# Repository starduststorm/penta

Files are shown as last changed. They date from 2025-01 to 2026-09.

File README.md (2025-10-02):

# penta

PCB designs and code for a Five-pointed star circumscribed within a circle of 55 pixels, for a total of 5³=125 pixels.

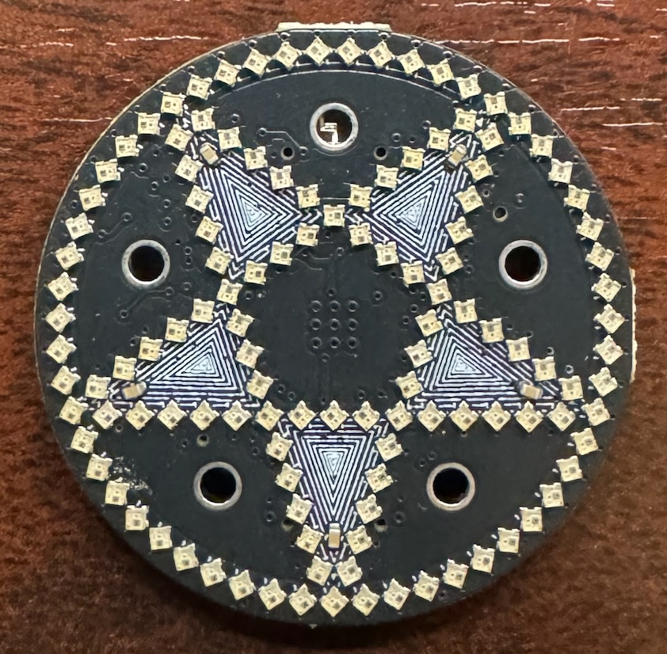
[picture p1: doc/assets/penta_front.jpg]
photo of front of penta

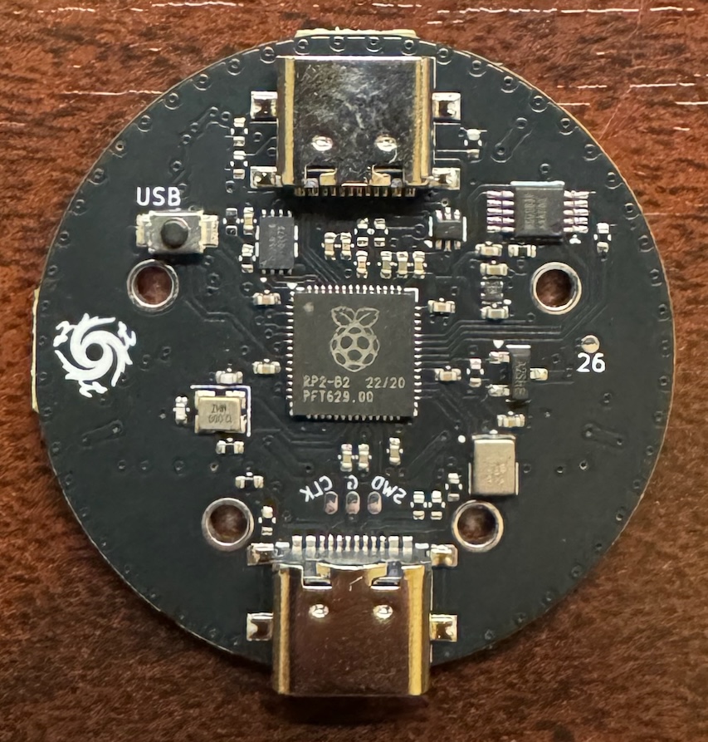
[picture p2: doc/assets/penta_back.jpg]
photo of back of penta


## Controls

The Five through-hole circles on the penta are touch-reactive and used to set the pattern.

## Hardware

* RP2040 dual-core ARM processor
* T3902 microphone
* WS2812B-1010 pixels

# Project layout

* board/ contains the KiCad pcb project
* src/ all project-specific source
* lib/ a skeleton copy of [kissfft], and submodule dependency *dustlib*

The project is built using [PlatformIO] in Visual Studio Code.

## Building

Build the v2 environment in the [PlatformIO] project, which corresponds to the MakerFaire2025 hardware.

You will likely need to run
```
git submodule update --init
```
in the source after ```git clone``` in order to fetch the submodule for building.

### Libraries & Dependencies
PlatformIO should fetch the apprpriate version of each dependency on first build.

* [FastLED] - A library for fast 8-bit math and rendering colors onto pixels
* [kissfft] - A simple library used to compute an fft on audio samples
* [dustlib] - My work-in-progress pixel library

[FastLED]: https://github.com/FastLED/FastLED
[PlatformIO]: <https://platformio.org>
[kissfft]: <https://github.com/mborgerding/kissfft>
[dustlib]: <https://github.com/starduststorm/dustlib>

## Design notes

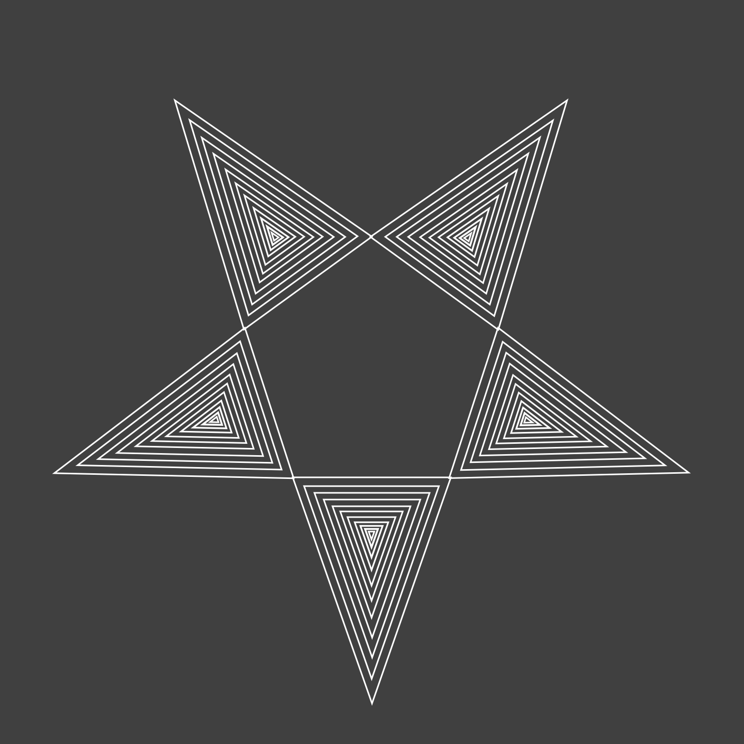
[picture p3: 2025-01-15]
board/assets/penta-brd-decor.png

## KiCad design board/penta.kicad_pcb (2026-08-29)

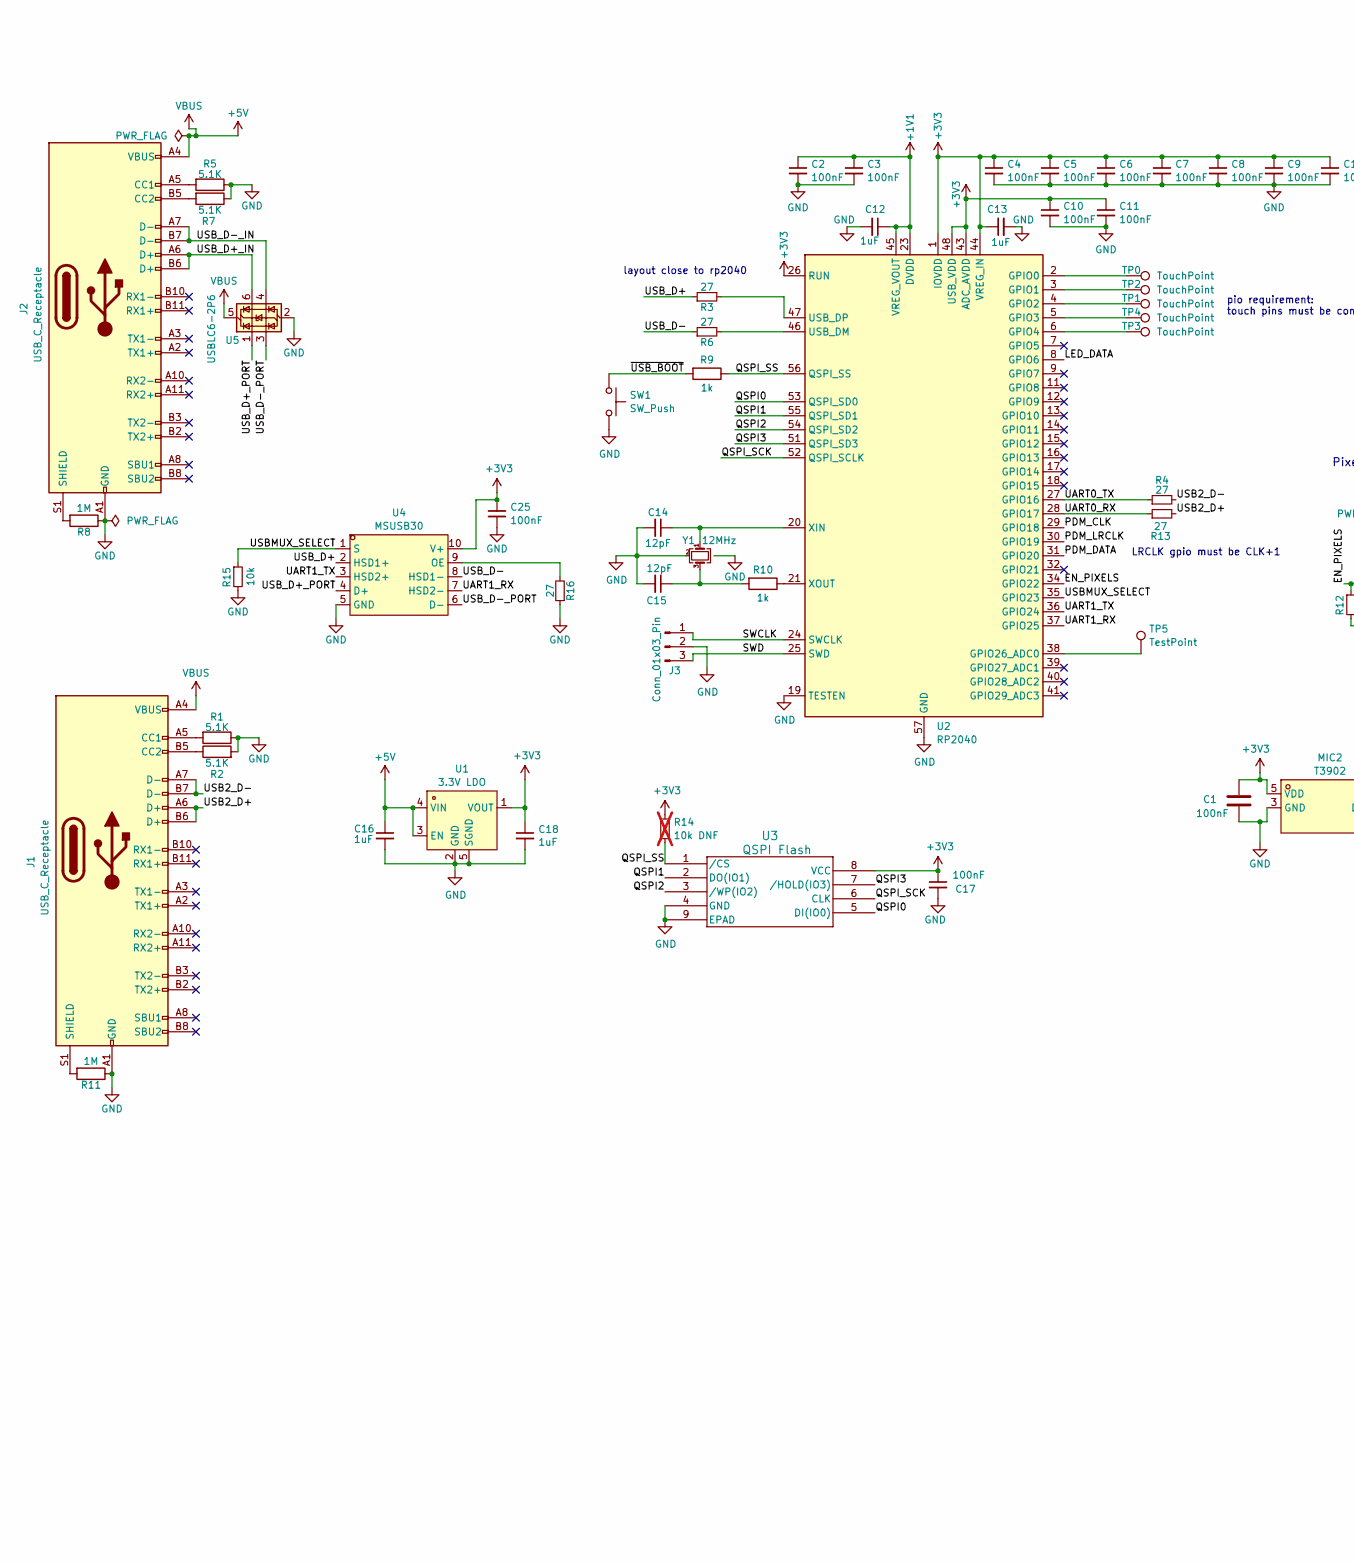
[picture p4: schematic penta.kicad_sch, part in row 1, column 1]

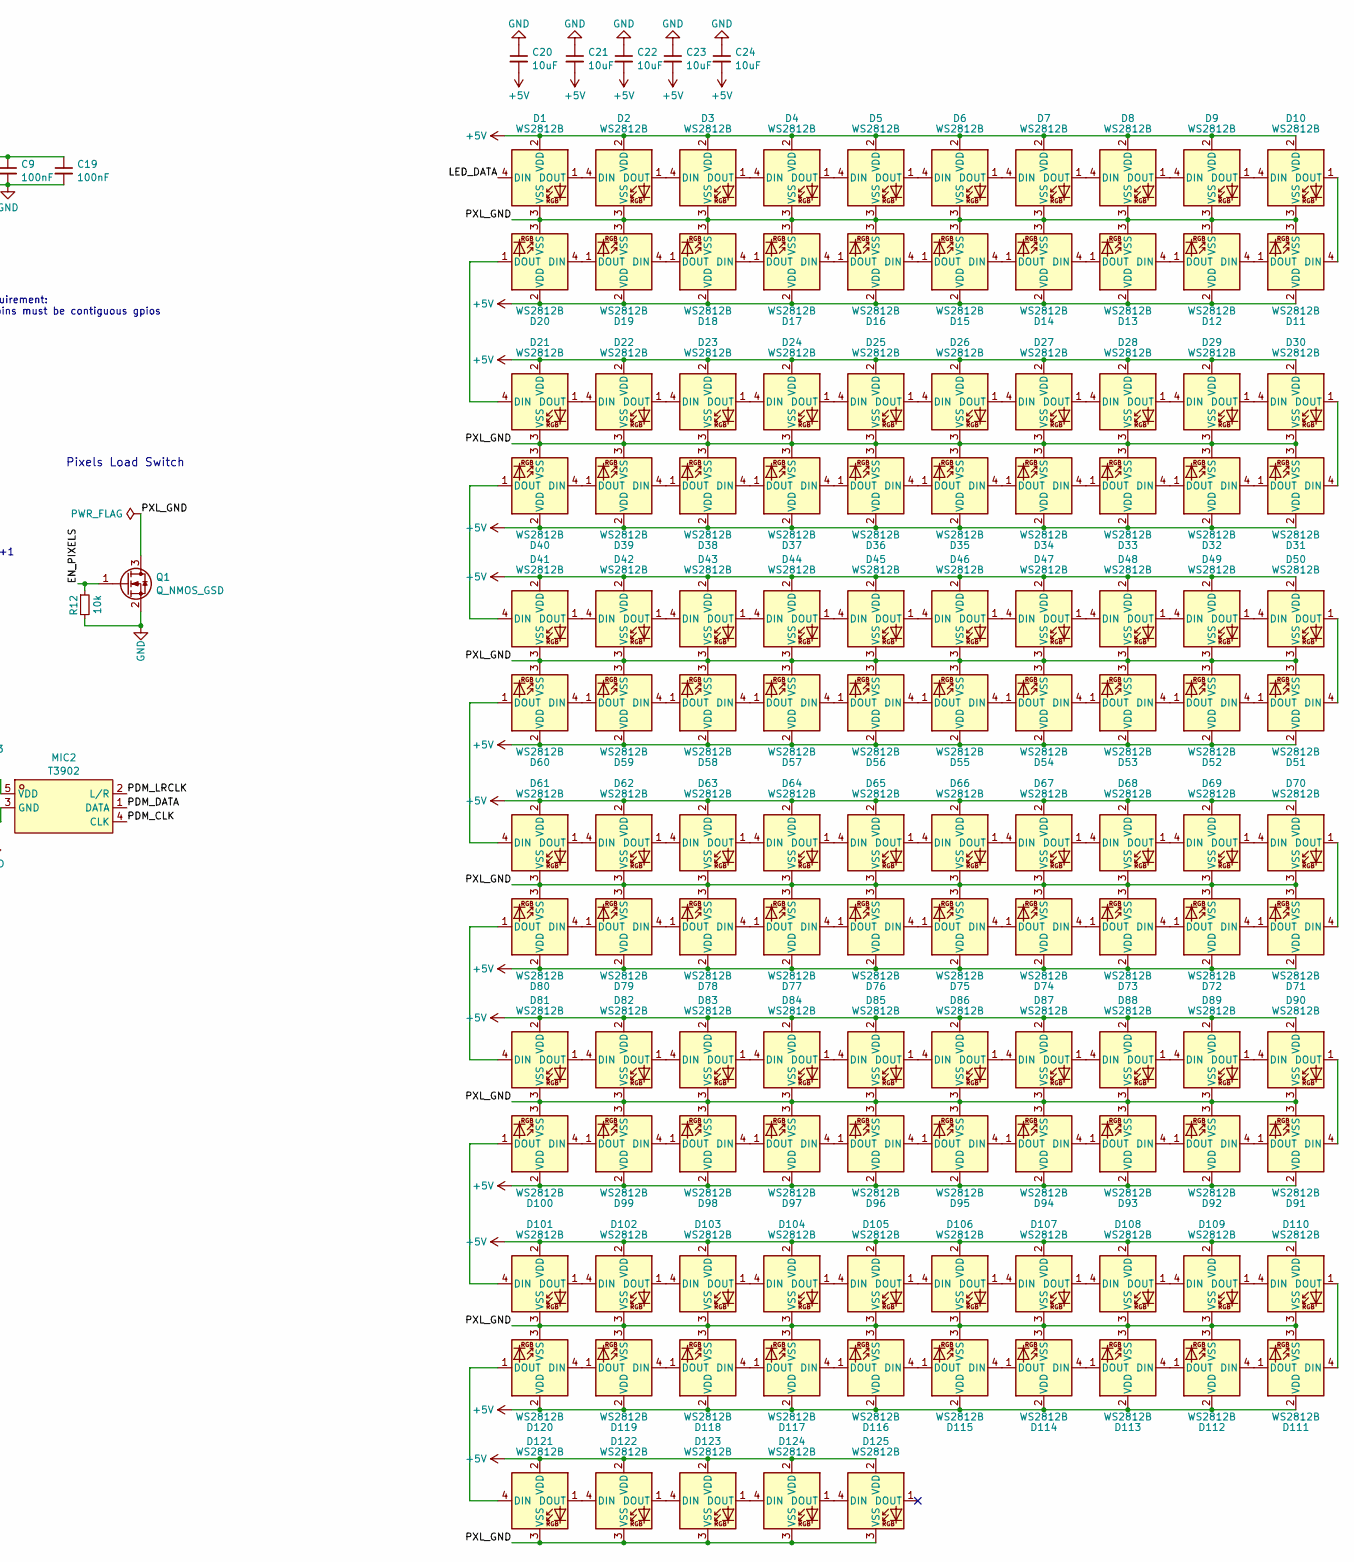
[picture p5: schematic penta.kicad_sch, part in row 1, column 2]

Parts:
C1, C2, C3, C4, C5, C6, C7, C8, C9, C10, C11, C17, C19, C25: 100nF; C_0402_1005Metric; LCSC C1525
C12, C13, C16, C18: 1uF; C_0402_1005Metric; LCSC C52923
C14, C15: 12pF; C_0402_1005Metric; LCSC C1547
C20, C21, C22, C23, C24: 10uF; C_0402_1005Metric; LCSC C15525
D1, D2, D3, D4, D5, D6, D7, D8, D9, D10, D11, D12, D13, D14, D15, D16, D17, D18, D19, D20, D21, D22, D23, D24, D25, D26, D27, D28, D29, D30, D31, D32, D33, D34, D35, D36, D37, D38, D39, D40, D41, D42, D43, D44, D45, D46, D47, D48, D49, D50, D51, D52, D53, D54, D55, D56, D57, D58, D59, D60, D61, D62, D63, D64, D65, D66, D67, D68, D69, D70, D71, D72, D73, D74, D75, D76, D77, D78, D79, D80, D81, D82, D83, D84, D85, D86, D87, D88, D89, D90, D91, D92, D93, D94, D95, D96, D97, D98, D99, D100, D101, D102, D103, D104, D105, D106, D107, D108, D109, D110, D111, D112, D113, D114, D115, D116, D117, D118, D119, D120, D121, D122, D123, D124, D125: WS2812B; ws2812b_1010; LCSC C5349953
J1, J2: USB_C_Receptacle; USB-SMD_USB-TYPE-C-020; LCSC C2927040
J3: Conn_01x03_Pin; SMD_Pad_01x03_1.27mm
MIC2: T3902; MIC_T3902; LCSC Part C3171752
Q1: Q_NMOS_GSD; SOT-23
R1, R2, R5, R7: 5.1K; R_0402_1005Metric; LCSC C25905
R3, R4, R6, R13, R16: 27; R_0402_1005Metric; LCSC C138021
R8, R11: 1M; R_0402_1005Metric; LCSC C26083
R9, R10: 1k; R_0402_1005Metric; LCSC C11702
R12, R15: 10k; R_0402_1005Metric; LCSC C25744
R14: 10k DNF; R_0402_1005Metric; not fitted
SW1: SW_Push; KEY-SMD_L3.0-W2.5-LS4.0; LCSC C2905190
TP0, TP1, TP2, TP3, TP4: TouchPoint; ScrewTouchHole
TP5: TestPoint; TestPoint_Pad_D1.0mm
U1: 3.3V LDO; OnSemi_XDFN4-1EP_1.0x1.0mm_EP0.52x0.52mm; LCSC Part C147954
U2: RP2040; QFN-56-1EP_7x7mm_P0.4mm_EP3.2x3.2mm; LCSC C2040
U3: QSPI Flash; USON_3X2_WIN; LCSC C7304007
U4: MSUSB30; MSOP-10_3x3mm_P0.5mm; LCSC Part C231929
U5: USBLC6-2P6; SOT-666; LCSC C2827693
Y1: 12MHz; Crystal_SMD_2520-4Pin_2.5x2.0mm; LCSC C284155

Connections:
+1V1: C2.1, C3.1, C12.1, U2.23 (DVDD), U2.45 (VREG_VOUT), U2.50 (DVDD)
+3V3: C1.1, C4.1, C5.1, C6.1, C7.1, C8.1, C9.1, C10.1, C11.1, C13.1, C17.1, C18.1, C19.1, C25.2, MIC2.5 (VDD), R14.1, U1.1 (VOUT), U2.1 (IOVDD), U2.10 (IOVDD), U2.22 (IOVDD), U2.26 (RUN), U2.33 (IOVDD), U2.42 (IOVDD), U2.43 (ADC_AVDD), U2.44 (VREG_IN), U2.48 (USB_VDD), U2.49 (IOVDD), U3.8 (VCC), U4.10 (V+)
+5V: C16.1, C20.2, C21.2, C22.2, C23.2, C24.2, D1.2 (VDD), D2.2 (VDD), D3.2 (VDD), D4.2 (VDD), D5.2 (VDD), D6.2 (VDD), D7.2 (VDD), D8.2 (VDD), D9.2 (VDD), D10.2 (VDD), D11.2 (VDD), D12.2 (VDD), D13.2 (VDD), D14.2 (VDD), D15.2 (VDD), D16.2 (VDD), D17.2 (VDD), D18.2 (VDD), D19.2 (VDD), D20.2 (VDD), D21.2 (VDD), D22.2 (VDD), D23.2 (VDD), D24.2 (VDD), D25.2 (VDD), D26.2 (VDD), D27.2 (VDD), D28.2 (VDD), D29.2 (VDD), D30.2 (VDD), D31.2 (VDD), D32.2 (VDD), D33.2 (VDD), D34.2 (VDD), D35.2 (VDD), D36.2 (VDD), D37.2 (VDD), D38.2 (VDD), D39.2 (VDD), D40.2 (VDD), D41.2 (VDD), D42.2 (VDD), D43.2 (VDD), D44.2 (VDD), D45.2 (VDD), D46.2 (VDD), D47.2 (VDD), D48.2 (VDD), D49.2 (VDD), D50.2 (VDD), D51.2 (VDD), D52.2 (VDD), D53.2 (VDD), D54.2 (VDD), D55.2 (VDD), D56.2 (VDD), D57.2 (VDD), D58.2 (VDD), D59.2 (VDD), D60.2 (VDD), D61.2 (VDD), D62.2 (VDD), D63.2 (VDD), D64.2 (VDD), D65.2 (VDD), D66.2 (VDD), D67.2 (VDD), D68.2 (VDD), D69.2 (VDD), D70.2 (VDD), D71.2 (VDD), D72.2 (VDD), D73.2 (VDD), D74.2 (VDD), D75.2 (VDD), D76.2 (VDD), D77.2 (VDD), D78.2 (VDD), D79.2 (VDD), D80.2 (VDD), D81.2 (VDD), D82.2 (VDD), D83.2 (VDD), D84.2 (VDD), D85.2 (VDD), D86.2 (VDD), D87.2 (VDD), D88.2 (VDD), D89.2 (VDD), D90.2 (VDD), D91.2 (VDD), D92.2 (VDD), D93.2 (VDD), D94.2 (VDD), D95.2 (VDD), D96.2 (VDD), D97.2 (VDD), D98.2 (VDD), D99.2 (VDD), D100.2 (VDD), D101.2 (VDD), D102.2 (VDD), D103.2 (VDD), D104.2 (VDD), D105.2 (VDD), D106.2 (VDD), D107.2 (VDD), D108.2 (VDD), D109.2 (VDD), D110.2 (VDD), D111.2 (VDD), D112.2 (VDD), D113.2 (VDD), D114.2 (VDD), D115.2 (VDD), D116.2 (VDD), D117.2 (VDD), D118.2 (VDD), D119.2 (VDD), D120.2 (VDD), D121.2 (VDD), D122.2 (VDD), D123.2 (VDD), D124.2 (VDD), D125.2 (VDD), J1.A4 (VBUS), J1.A9 (VBUS), J1.B4 (VBUS), J1.B9 (VBUS), J2.A4 (VBUS), J2.A9 (VBUS), J2.B4 (VBUS), J2.B9 (VBUS), U1.3 (EN), U1.4 (VIN), U5.5 (VBUS)
/EN_PIXELS: Q1.1 (G), R12.1, U2.34 (GPIO22)
/LED_DATA: D1.4 (DIN), U2.8 (GPIO6)
/PDM_CLK: MIC2.4 (CLK), U2.29 (GPIO18)
/PDM_DATA: MIC2.1 (DATA), U2.31 (GPIO20)
/PDM_LRCLK: MIC2.2 (L/R), U2.30 (GPIO19)
/PXL_GND: D1.3 (VSS), D2.3 (VSS), D3.3 (VSS), D4.3 (VSS), D5.3 (VSS), D6.3 (VSS), D7.3 (VSS), D8.3 (VSS), D9.3 (VSS), D10.3 (VSS), D11.3 (VSS), D12.3 (VSS), D13.3 (VSS), D14.3 (VSS), D15.3 (VSS), D16.3 (VSS), D17.3 (VSS), D18.3 (VSS), D19.3 (VSS), D20.3 (VSS), D21.3 (VSS), D22.3 (VSS), D23.3 (VSS), D24.3 (VSS), D25.3 (VSS), D26.3 (VSS), D27.3 (VSS), D28.3 (VSS), D29.3 (VSS), D30.3 (VSS), D31.3 (VSS), D32.3 (VSS), D33.3 (VSS), D34.3 (VSS), D35.3 (VSS), D36.3 (VSS), D37.3 (VSS), D38.3 (VSS), D39.3 (VSS), D40.3 (VSS), D41.3 (VSS), D42.3 (VSS), D43.3 (VSS), D44.3 (VSS), D45.3 (VSS), D46.3 (VSS), D47.3 (VSS), D48.3 (VSS), D49.3 (VSS), D50.3 (VSS), D51.3 (VSS), D52.3 (VSS), D53.3 (VSS), D54.3 (VSS), D55.3 (VSS), D56.3 (VSS), D57.3 (VSS), D58.3 (VSS), D59.3 (VSS), D60.3 (VSS), D61.3 (VSS), D62.3 (VSS), D63.3 (VSS), D64.3 (VSS), D65.3 (VSS), D66.3 (VSS), D67.3 (VSS), D68.3 (VSS), D69.3 (VSS), D70.3 (VSS), D71.3 (VSS), D72.3 (VSS), D73.3 (VSS), D74.3 (VSS), D75.3 (VSS), D76.3 (VSS), D77.3 (VSS), D78.3 (VSS), D79.3 (VSS), D80.3 (VSS), D81.3 (VSS), D82.3 (VSS), D83.3 (VSS), D84.3 (VSS), D85.3 (VSS), D86.3 (VSS), D87.3 (VSS), D88.3 (VSS), D89.3 (VSS), D90.3 (VSS), D91.3 (VSS), D92.3 (VSS), D93.3 (VSS), D94.3 (VSS), D95.3 (VSS), D96.3 (VSS), D97.3 (VSS), D98.3 (VSS), D99.3 (VSS), D100.3 (VSS), D101.3 (VSS), D102.3 (VSS), D103.3 (VSS), D104.3 (VSS), D105.3 (VSS), D106.3 (VSS), D107.3 (VSS), D108.3 (VSS), D109.3 (VSS), D110.3 (VSS), D111.3 (VSS), D112.3 (VSS), D113.3 (VSS), D114.3 (VSS), D115.3 (VSS), D116.3 (VSS), D117.3 (VSS), D118.3 (VSS), D119.3 (VSS), D120.3 (VSS), D121.3 (VSS), D122.3 (VSS), D123.3 (VSS), D124.3 (VSS), D125.3 (VSS), Q1.3 (D)
/QSPI0: U2.53 (QSPI_SD0), U3.5 (DI(IO0))
/QSPI1: U2.55 (QSPI_SD1), U3.2 (DO(IO1))
/QSPI2: U2.54 (QSPI_SD2), U3.3 (/WP(IO2))
/QSPI3: U2.51 (QSPI_SD3), U3.7 (/HOLD(IO3))
/QSPI_SCK: U2.52 (QSPI_SCLK), U3.6 (CLK)
/QSPI_SS: R9.1, R14.2, U2.56 (QSPI_SS), U3.1 (/CS)
/SWCLK: J3.1, U2.24 (SWCLK)
/SWD: J3.3, U2.25 (SWD)
/UART0_RX: R13.1, U2.28 (GPIO17)
/UART0_TX: R4.1, U2.27 (GPIO16)
/UART1_RX: U2.37 (GPIO25), U4.7 (HSD2-)
/UART1_TX: U2.36 (GPIO24), U4.3 (HSD2+)
/USB2_D+: J1.A6 (D+), J1.B6 (D+), R13.2
/USB2_D-: J1.A7 (D-), J1.B7 (D-), R4.2
/USBMUX_SELECT: R15.1, U2.35 (GPIO23), U4.1 (S)
/USB_D+: R3.1, U4.2 (HSD1+)
/USB_D+_IN: J2.A6 (D+), J2.B6 (D+), U5.6 (I/O1)
/USB_D+_PORT: U4.4 (D+), U5.1 (I/O1)
/USB_D-: R6.1, U4.8 (HSD1-)
/USB_D-_IN: J2.A7 (D-), J2.B7 (D-), U5.4 (I/O2)
/USB_D-_PORT: U4.6 (D-), U5.3 (I/O2)
/~USB_BOOT: R9.2, SW1.1
GND: C1.2, C2.2, C3.2, C4.2, C5.2, C6.2, C7.2, C8.2, C9.2, C10.2, C11.2, C12.2, C13.2, C14.2, C15.2, C16.2, C17.2, C18.2, C19.2, C20.1, C21.1, C22.1, C23.1, C24.1, C25.1, J1.A1 (GND), J1.A12 (GND), J1.B1 (GND), J1.B12 (GND), J2.A1 (GND), J2.A12 (GND), J2.B1 (GND), J2.B12 (GND), J3.2, MIC2.3 (GND), Q1.2 (S), R1.1, R2.2, R5.1, R7.1, R8.1, R11.1, R12.2, R15.2, R16.1, SW1.2, U1.2 (GND), U1.5 (SGND), U2.19 (TESTEN), U2.57 (GND), U3.4 (GND), U3.9 (EPAD), U4.5 (GND), U5.2 (GND), Y1.2 (G), Y1.4 (G)
unnamed: C15.1, R10.2, Y1.3
unnamed: D1.1 (DOUT), D2.4 (DIN)
unnamed: D2.1 (DOUT), D3.4 (DIN)
unnamed: D3.1 (DOUT), D4.4 (DIN)
unnamed: D4.1 (DOUT), D5.4 (DIN)
unnamed: D5.1 (DOUT), D6.4 (DIN)
unnamed: D6.1 (DOUT), D7.4 (DIN)
unnamed: D7.1 (DOUT), D8.4 (DIN)
unnamed: D8.1 (DOUT), D9.4 (DIN)
unnamed: D9.1 (DOUT), D10.4 (DIN)
unnamed: D10.1 (DOUT), D11.4 (DIN)
unnamed: D11.1 (DOUT), D12.4 (DIN)
unnamed: D12.1 (DOUT), D13.4 (DIN)
unnamed: D13.1 (DOUT), D14.4 (DIN)
unnamed: D14.1 (DOUT), D15.4 (DIN)
unnamed: D15.1 (DOUT), D16.4 (DIN)
unnamed: D16.1 (DOUT), D17.4 (DIN)
unnamed: D17.1 (DOUT), D18.4 (DIN)
unnamed: D18.1 (DOUT), D19.4 (DIN)
unnamed: D19.1 (DOUT), D20.4 (DIN)
unnamed: D20.1 (DOUT), D21.4 (DIN)
unnamed: D21.1 (DOUT), D22.4 (DIN)
unnamed: D22.1 (DOUT), D23.4 (DIN)
unnamed: D23.1 (DOUT), D24.4 (DIN)
unnamed: D24.1 (DOUT), D25.4 (DIN)
unnamed: D25.1 (DOUT), D26.4 (DIN)
unnamed: D26.1 (DOUT), D27.4 (DIN)
unnamed: D27.1 (DOUT), D28.4 (DIN)
unnamed: D28.1 (DOUT), D29.4 (DIN)
unnamed: D29.1 (DOUT), D30.4 (DIN)
unnamed: D30.1 (DOUT), D31.4 (DIN)
unnamed: D31.1 (DOUT), D32.4 (DIN)
unnamed: D32.1 (DOUT), D33.4 (DIN)
unnamed: D33.1 (DOUT), D34.4 (DIN)
unnamed: D34.1 (DOUT), D35.4 (DIN)
unnamed: D35.1 (DOUT), D36.4 (DIN)
unnamed: D36.1 (DOUT), D37.4 (DIN)
unnamed: D37.1 (DOUT), D38.4 (DIN)
unnamed: D38.1 (DOUT), D39.4 (DIN)
unnamed: D39.1 (DOUT), D40.4 (DIN)
unnamed: D40.1 (DOUT), D41.4 (DIN)
unnamed: D41.1 (DOUT), D42.4 (DIN)
unnamed: D42.1 (DOUT), D43.4 (DIN)
unnamed: D43.1 (DOUT), D44.4 (DIN)
unnamed: D44.1 (DOUT), D45.4 (DIN)
unnamed: D45.1 (DOUT), D46.4 (DIN)
unnamed: D46.1 (DOUT), D47.4 (DIN)
unnamed: D47.1 (DOUT), D48.4 (DIN)
unnamed: D48.1 (DOUT), D49.4 (DIN)
unnamed: D49.1 (DOUT), D50.4 (DIN)
unnamed: D50.1 (DOUT), D51.4 (DIN)
unnamed: D51.1 (DOUT), D52.4 (DIN)
unnamed: D52.1 (DOUT), D53.4 (DIN)
unnamed: D53.1 (DOUT), D54.4 (DIN)
unnamed: D54.1 (DOUT), D55.4 (DIN)
unnamed: D55.1 (DOUT), D56.4 (DIN)
unnamed: D56.1 (DOUT), D57.4 (DIN)
unnamed: D57.1 (DOUT), D58.4 (DIN)
unnamed: D58.1 (DOUT), D59.4 (DIN)
unnamed: D59.1 (DOUT), D60.4 (DIN)
unnamed: D60.1 (DOUT), D61.4 (DIN)
unnamed: D61.1 (DOUT), D62.4 (DIN)
unnamed: D62.1 (DOUT), D63.4 (DIN)
unnamed: D63.1 (DOUT), D64.4 (DIN)
unnamed: D64.1 (DOUT), D65.4 (DIN)
unnamed: D65.1 (DOUT), D66.4 (DIN)
unnamed: D66.1 (DOUT), D67.4 (DIN)
unnamed: D67.1 (DOUT), D68.4 (DIN)
unnamed: D68.1 (DOUT), D69.4 (DIN)
unnamed: D69.1 (DOUT), D70.4 (DIN)
unnamed: D70.1 (DOUT), D71.4 (DIN)
unnamed: D71.1 (DOUT), D72.4 (DIN)
unnamed: D72.1 (DOUT), D73.4 (DIN)
unnamed: D73.1 (DOUT), D74.4 (DIN)
unnamed: D74.1 (DOUT), D75.4 (DIN)
unnamed: D75.1 (DOUT), D76.4 (DIN)
unnamed: D76.1 (DOUT), D77.4 (DIN)
unnamed: D77.1 (DOUT), D78.4 (DIN)
unnamed: D78.1 (DOUT), D79.4 (DIN)
unnamed: D79.1 (DOUT), D80.4 (DIN)
unnamed: D80.1 (DOUT), D81.4 (DIN)
unnamed: D81.1 (DOUT), D82.4 (DIN)
unnamed: D82.1 (DOUT), D83.4 (DIN)
unnamed: D83.1 (DOUT), D84.4 (DIN)
unnamed: D84.1 (DOUT), D85.4 (DIN)
unnamed: D85.1 (DOUT), D86.4 (DIN)
unnamed: D86.1 (DOUT), D87.4 (DIN)
unnamed: D87.1 (DOUT), D88.4 (DIN)
unnamed: D88.1 (DOUT), D89.4 (DIN)
unnamed: D89.1 (DOUT), D90.4 (DIN)
unnamed: D90.1 (DOUT), D91.4 (DIN)
unnamed: D91.1 (DOUT), D92.4 (DIN)
unnamed: D92.1 (DOUT), D93.4 (DIN)
unnamed: D93.1 (DOUT), D94.4 (DIN)
unnamed: D94.1 (DOUT), D95.4 (DIN)
unnamed: D95.1 (DOUT), D96.4 (DIN)
unnamed: D96.1 (DOUT), D97.4 (DIN)
unnamed: D97.1 (DOUT), D98.4 (DIN)
unnamed: D98.1 (DOUT), D99.4 (DIN)
unnamed: D99.1 (DOUT), D100.4 (DIN)
unnamed: D100.1 (DOUT), D101.4 (DIN)
unnamed: D101.1 (DOUT), D102.4 (DIN)
unnamed: D102.1 (DOUT), D103.4 (DIN)
unnamed: D103.1 (DOUT), D104.4 (DIN)
unnamed: D104.1 (DOUT), D105.4 (DIN)
unnamed: D105.1 (DOUT), D106.4 (DIN)
unnamed: D106.1 (DOUT), D107.4 (DIN)
unnamed: D107.1 (DOUT), D108.4 (DIN)
unnamed: D108.1 (DOUT), D109.4 (DIN)
unnamed: D109.1 (DOUT), D110.4 (DIN)
unnamed: D110.1 (DOUT), D111.4 (DIN)
unnamed: D111.1 (DOUT), D112.4 (DIN)
unnamed: D112.1 (DOUT), D113.4 (DIN)
unnamed: D113.1 (DOUT), D114.4 (DIN)
unnamed: D114.1 (DOUT), D115.4 (DIN)
unnamed: D115.1 (DOUT), D116.4 (DIN)
unnamed: D116.1 (DOUT), D117.4 (DIN)
unnamed: D117.1 (DOUT), D118.4 (DIN)
unnamed: D118.1 (DOUT), D119.4 (DIN)
unnamed: D119.1 (DOUT), D120.4 (DIN)
unnamed: D120.1 (DOUT), D121.4 (DIN)
unnamed: D121.1 (DOUT), D122.4 (DIN)
unnamed: D122.1 (DOUT), D123.4 (DIN)
unnamed: D123.1 (DOUT), D124.4 (DIN)
unnamed: D124.1 (DOUT), D125.4 (DIN)
unnamed: J1.A5 (CC1), R1.2
unnamed: J1.B5 (CC2), R2.1
unnamed: J1.S1 (SHIELD), R11.2
unnamed: J2.A5 (CC1), R5.2
unnamed: J2.B5 (CC2), R7.2
unnamed: J2.S1 (SHIELD), R8.2
unnamed: TP0.1, U2.2 (GPIO0)
unnamed: TP2.1, U2.3 (GPIO1)
unnamed: TP1.1, U2.4 (GPIO2)
unnamed: TP4.1, U2.5 (GPIO3)
unnamed: TP3.1, U2.6 (GPIO4)
unnamed: TP5.1, U2.38 (GPIO26_ADC0)
unnamed: R6.2, U2.46 (USB_DM)
unnamed: R3.2, U2.47 (USB_DP)
unnamed: C14.1, U2.20 (XIN), Y1.1
unnamed: R10.1, U2.21 (XOUT)
unnamed: R16.2, U4.9 (OE)

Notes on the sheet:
layout close to rp2040
LRCLK gpio must be CLK+1
Pixels Load Switch
pio requirement: touch pins must be contiguous gpios

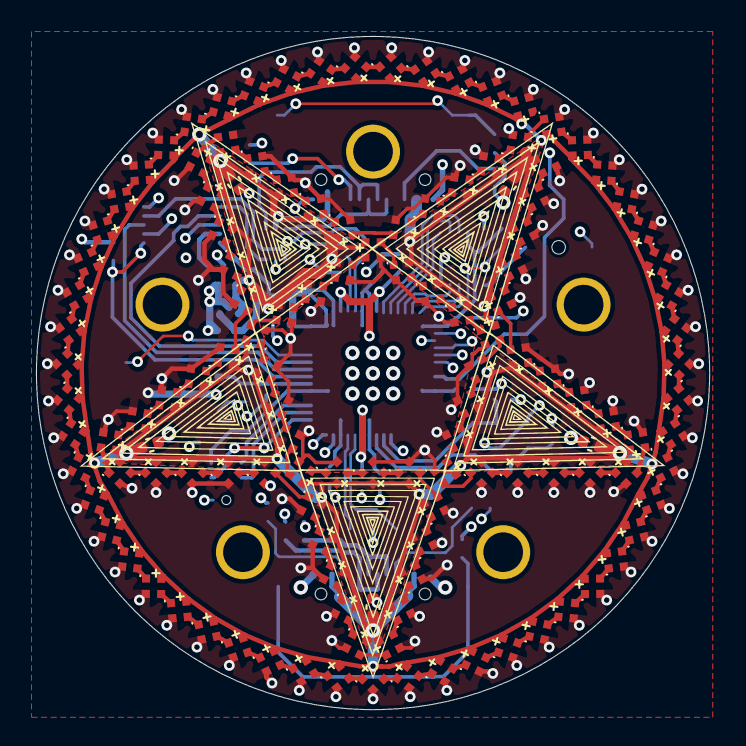
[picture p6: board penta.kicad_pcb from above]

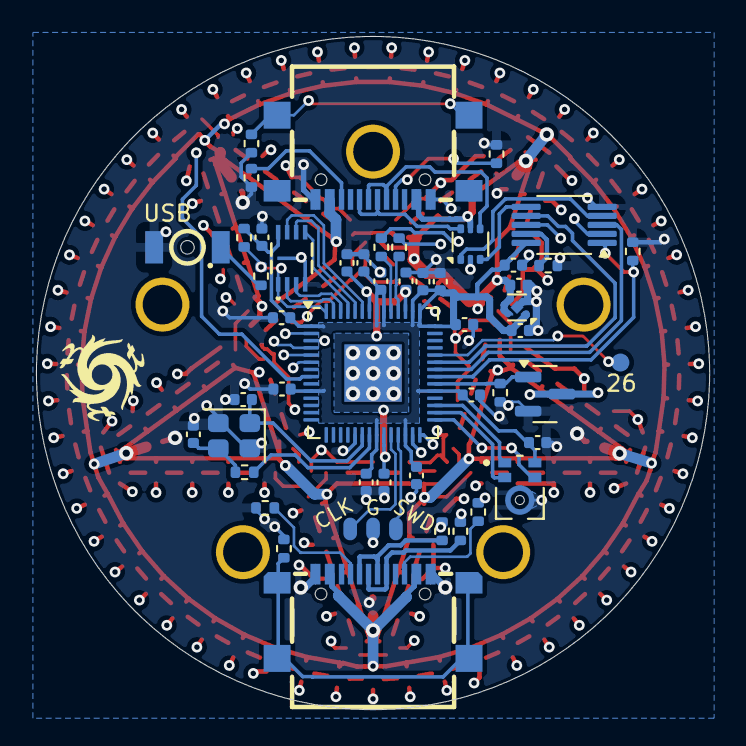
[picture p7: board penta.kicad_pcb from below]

Board: 4 copper layers, 37.4 x 37.4 mm, 184 parts (49 on the bottom side), 174 nets.

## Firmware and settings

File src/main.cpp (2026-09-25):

 // penta main.cpp
#define DEBUG 0
#define WAIT_FOR_SERIAL 0
#define LOG_BOOT_CAPTURE_BYTES 2048 // keep the boot log for HWTEST

#define FIVE (5)

// for memory logging
#ifdef __arm__
extern "C" char* sbrk(int incr);
#else
extern char *__brkval;
#endif

#include <stdio.h>
#include "pico.h"
#include "pico/stdlib.h"
#include "hardware/pio.h"

#include <Arduino.h>
#include <SPI.h>

#define USE_AUTOMODES true

#if HARDWARE_VERSION >= 2

#define LED_DATA 6
#define LED_LINE_0_POWER 22

#define USBMUX_SELECT 23
#define UART0_TX 16
#define UART0_RX 17

#define UART1_TX 24
#define UART1_RX 25

#define PIN_PDM_DIN 20
#define PIN_PDM_CLK 18

#define UNCONNECTED_PIN_1 27
#define UNCONNECTED_PIN_2 28

#elif HARDWARE_VERSION == 1

#define LED_DATA 26
#define LED_LINE_0_POWER 27

#define PIN_PDM_DIN 6
#define PIN_PDM_CLK 28

#define UNCONNECTED_PIN_1 7
#define UNCONNECTED_PIN_2 7

#endif

#include <pico/unique_id.h>
extern "C" bool tud_mounted(void); // TinyUSB: has a USB host configured us?
#include "piouart.h"
// Main USB port muxed to UART1 (Serial2) pins, secondary USB port wired to UART0 (Serial1).
// We'll use hardware UART when the pins line up, and a PIO UART when tx/rx are swapped.
//
// PIO placement is pinned (see piouart.h): both swapped RX on pio0 (sharing the
// 9-word rx program + PIO0_IRQ_0), both swapped TX on pio1, with touch on pio1
// (IRQ1), FastLED on pio0, leaving PDM a guaranteed slot. SMs are claimed
// permanently via reserve() in setup(); orientation changes are funcsel swaps.
//   pio0: SM0 FastLED, SM1 port0 RX, SM2 port1 RX, SM3 PDM(auto)
//   pio1: SM0 ccount,  SM1 touch,    SM2 port0 TX, SM3 port1 TX
// Link baud. Both engines derive from it; the pads are 2mA/slow-slew so keep it
// under a few Mbaud. 921600 makes a firmware push take a couple of seconds.
#define LINK_BAUD 921600
PioUart port0Swapped(/*tx*/ pio1, UART0_RX /*17*/, /*rx*/ pio0, UART0_TX /*16*/, LINK_BAUD);
PioUart port1Swapped(/*tx*/ pio1, UART1_RX /*25*/, /*rx*/ pio0, UART1_TX /*24*/, LINK_BAUD);

#include <audio.h>

// The T3902's select pin (PDM_LRCLK, GPIO19) has no pull on the board, so it
// must be driven or each unit's mic picks a clock edge at random and some read
// as a flat line. Drive it HIGH (dustlib's fixSelectHIGH) -- the level the
// arduino-pico PDM sampler expects.
AudioInputPDM audioInput(PIN_PDM_DIN, PIN_PDM_CLK, /*fixSelectHIGH*/ true);
FFTProcessing fftProcessing(audioInput, 10, 128);
// keeps the mic streaming amplitude measurements for sound patterns' run conditions
AmplitudeReceiver *ambientSound = NULL;

#undef FASTLED_USE_PROGMEM
#define FASTLED_USE_PROGMEM 1
#define FASTLED_USE_GLOBAL_BRIGHTNESS 1
#define kDefaultBrightness 20
// #define FASTLED_ALLOW_INTERRUPTS 0
#include <functional>
#include <FastLED.h>

#include <util.h>
#include <drawing.h>
#include <controls.h>
#include <touchpio.h>

#include "uartlink.h" // needs logf() from util.h
// Two independent auto-negotiating links, one per port.
SerialLink link0("link0", Serial1, port0Swapped, UART0_TX, UART0_RX, LINK_BAUD);
SerialLink link1("link1", Serial2, port1Swapped, UART1_TX, UART1_RX, LINK_BAUD);

// Port roles: the "main" port is J2 (USB, muxed to UART1 = link1), the "alt"
// port is J1 (UART0 = link0). Topology counts are reported per side.
#define ALT_PORT 0
#define MAIN_PORT 1

#include "topology.h"
#include "neighborhood.h"
#include "usbmux.h"
// Keeps J2 pointed at a computer or at the chain, whichever is actually there.
UsbMuxArbiter usbMux;
#include "fwpush.h"
// Chain discovery: how many pentas sit on each side of us, and the total.
ChainTopology topology;
// Chain-coordinated automodes: each periodic animation is a wave passed board
// to board over the links (see neighborhood.h), replacing the old clock-based
// sawtoothEvery() timing with its per-board phase offsets.
PatternNeighborhoods neighborhoods;
PatternNeighborhood automodes[FIVE];
// Firmware propagation: push our image to a neighbor over the link.
FirmwarePush fwPush;

static void peerBlink();

static void onLinkData(const char *name, int port, const uint8_t *d, uint8_t n) {
  if (topology.onData(port, d, n)) return; // topology probes are consumed here
  if (neighborhoods.onData(port, d, n)) return;
  if (fwPush.onData(port, d, n)) return;
  logf("[%s] rx %u bytes: %.*s", name, n, n, (const char *)d);
  
  // Demo traffic: log DATA frames from each port; a "blink" payload blinks us.
  if (n == 5 && memcmp(d, "blink", 5) == 0) {
    peerBlink();
  }
}
static void onLink0Data(const uint8_t *d, uint8_t n) { onLinkData("link0", ALT_PORT, d, n); }
static void onLink1Data(const uint8_t *d, uint8_t n) { onLinkData("link1", MAIN_PORT, d, n); }

#include "ledgraph.h"

#include <patterning.h>
#include "patterns.h"

#include <remembering.h>
#include <updating.h>
#include <fw_version.h> // FW_VERSION, generated from the fw-v* tag by lib/dustlib/scripts/fw_version.py
PersistentStorage storage(PentaState::dataSize());

/////////////////////

DrawingContext ctx;
PatternManager patternManager(ctx);

static void peerBlink() {
  static constexpr unsigned long kFlashPeriodMs = 250;
  static constexpr int kFlashes = 3;
  patternManager.runOneShotDrawing([](DrawingContext &c, unsigned long elapsed) {
    if (elapsed >= kFlashes * kFlashPeriodMs) return false;
    c.leds.fill_solid(CRGB::Black);
    if ((elapsed % kFlashPeriodMs) < kFlashPeriodMs / 2) {
      for (PixelIndex px : kCircleLeds) {
        c.leds[px] = CRGB::Cyan;
      }
    }
    return true;
  }, patternManager.highestPriority());
}

HardwareControls controls;
FrameCounter fc;

static bool serialTimeout = false;
static unsigned long setupDoneTime;
static bool powerOn = true;

// map from touch button wiring order to logical button index
#if HARDWARE_VERSION >= 2
int touchIndexMap[FIVE] = {0,2,1,4,3};
#else
int touchIndexMap[FIVE] = {0,1,2,3,4};
#endif

#define TOUCH_PIN 0 // GPIO number for the first touch button
#define TOUCH_COUNT FIVE // number of sequential touch buttons
TouchPIO touch;

// How many instruction words a PIO still has free. pio_can_add_program only
// checks space for a relocatable program, so probe with descending sizes.
static int pioFreeInstructionWords(PIO pio) {
  static const uint16_t dummyInsns[32] = {0}; // never executed
  for (int len = 32; len > 0; --len) {
    pio_program_t p = { .instructions = dummyInsns, .length = (uint8_t)len, .origin = -1 };
    if (pio_can_add_program(pio, &p)) {
      return len;
    }
  }
  return 0;
}

// Fail-loudly snapshot of the shared PIO resources, called once everything in
// setup() has claimed its slots. 2 PIOs x 4 SMs and 32 instruction words per
// PIO are the whole budget; logging who holds what makes a setup() reshuffle
// show up as a diff here instead of a mystery failure in whichever subsystem
// lost its slot. Expected steady-state map (see piouart.h):
//   pio0: SM0 FastLED, SM1 p0 rx, SM2 p1 rx, SM3 PDM (auto-claimed)
//   pio1: SM0 ccount,  SM1 touch, SM2 p0 tx, SM3 p1 tx
void verifyPioLayout() {
  for (int p = 0; p < 2; ++p) {
    PIO pio = p == 0 ? pio0 : pio1;
    char claimed[5];
    for (int sm = 0; sm < 4; ++sm) {
      claimed[sm] = pio_sm_is_claimed(pio, sm) ? ('0' + sm) : '.';
    }
    claimed[4] = 0;
    logf("[pio%d] claimed SMs [%s], %d/32 instruction words free",
         p, claimed, pioFreeInstructionWords(pio));
  }
  logf("[pio] uart SMs: p0 rx=%d tx=%d, p1 rx=%d tx=%d; touch sm=%d",
       port0Swapped.rxSM(), port0Swapped.txSM(),
       port1Swapped.rxSM(), port1Swapped.txSM(), touch.sm());
  assert(port0Swapped.reserved(), "port0 swapped uart failed to reserve PIO resources");
  assert(port1Swapped.reserved(), "port1 swapped uart failed to reserve PIO resources");
}

void init_serial() {
  Serial.begin(57600);
#if WAIT_FOR_SERIAL
  long setupStart = millis();
  while (!Serial) {
    if (millis() - setupStart > 10000) {
      serialTimeout = true;
      break;
    }
  }
  delay(100);
  logf("begin - waited %ims for Serial", millis() - setupStart);
#elif DEBUG
  delay(2000);
  Serial.println("Done waiting at boot.");
#endif
}

void serialTimeoutIndicator() {
  FastLED.setBrightness(10);
  gpio_put(LED_LINE_0_POWER, true);
  ctx.leds.fill_solid(CRGB::Black);
  if ((millis() - setupDoneTime) % 250 < 100) {
    ctx.leds.fill_solid(CRGB::Red);
  }
  FastLED.show();
  delay(20);
}

void startupWelcome() {
  int welcomeDuration = 555;

  CRGB color = CRGB::Purple; // FIXME: get from saved
  uint8_t offset = 16 * random(FIVE); // FIXME: get from saved

  patternManager.runOneShotDrawing([welcomeDuration, color, offset](DrawingContext &c, unsigned long elapsed) {
    c.leds.fadeToBlackBy(5);
    if (elapsed < (unsigned long)welcomeDuration) {
      uint16_t progress = ease16InOutQuad(0xFFFF * elapsed/welcomeDuration);
      PixelIndex px = kStarwiseLeds[(kStarwiseLeds.size() * progress / 0xFFFF + offset) % kStarwiseLeds.size()];
      c.leds[px] = color;
      return true;
    }
    return (bool)c.leds; // after the sweep, keep fading until fully black
  }, patternManager.highestPriority());
}

// SETUP ///////////////////////////////////////////////

// TODO: the idea was to have each arrow's timed/coordinated patterns be toggled on and off with long-press
//   this touch-feedback and animation could be improved.

void reachableFrom(ParticleSim<LED_COUNT> &sim, std::vector<PixelIndex> &insertInto, std::set<PixelIndex> &visited, Particle &p, PixelIndex fromPx, EdgeTypesQuad directions) {
  // FIXME: this stops at the first path self-intersection

  visited.insert(fromPx);
  insertInto.push_back(fromPx);
  for (auto edge : sim.edgeCandidates(p)) {
    if (visited.find(edge.to) == visited.end()) {
      p.lastPx = p.px;
      p.px = edge.to;
      reachableFrom(sim, insertInto, visited, p, edge.to, directions);
    } else {
      // 
    }
  }
}
void reachableFrom(ParticleSim<LED_COUNT> &sim, std::vector<PixelIndex> &insertInto, PixelIndex fromPx, EdgeTypesQuad directions) {
  uint8_t particleIndex = sim.particles.size();
  auto &p = sim.addParticle();
  p.px = fromPx;
  p.directions = directions;
  std::set<PixelIndex> visited;
  reachableFrom(sim, insertInto, visited, p ,fromPx, directions);
  sim.removeParticle(particleIndex);
}

std::vector<PixelIndex> arrows[FIVE];
void findArrows() {
  logf("find arrows");
  // find arrows
  // FIXME: this may have a bug, since trying to do it on demand was bringing up a weird timing bug 
  for (int mode = 0; mode < FIVE; ++mode) {
    std::vector<PixelIndex> fromStarwise, fromCounterStarwise;
    ParticleSim<LED_COUNT> sim(ledgraph, ctx, 0, 0, 0, {starwise});
    sim.followContinueTo = true;
    sim.preventReverseFlow = true;
    sim.flowRule = ParticleSim<LED_COUNT>::priority;
  
    reachableFrom(sim, fromStarwise, kTrianglePointLeds[mode], MakeEdgeTypesQuad(starwise));
    reachableFrom(sim, fromCounterStarwise, kTrianglePointLeds[mode], MakeEdgeTypesQuad(counterstarwise));
  
    arrows[mode] = {kTrianglePointLeds[mode]};
    // skip the pixel we started on
    for (int i = 1; i < min(fromStarwise.size(), fromCounterStarwise.size()); ++i) {
      arrows[mode].push_back(fromStarwise[i]);
      if (fromStarwise[i] == fromCounterStarwise[i]) {
        break;
      }
      arrows[mode].push_back(fromCounterStarwise[i]);
    }
    assert(fromStarwise.size() == fromCounterStarwise.size(), "wtf");
    
    assert(arrows[mode].size() == 44, "bad arrow found"); // FIXME: does this happen?
  }
}

IndexedPatternRunner *indexedRunner = NULL;
ConditionalPatternRunner *periodics[5] = {0};

ArrowBits *allArrowBits[FIVE] = {0};

unsigned long lastModeChoose = 0;
void chooseMode(int mode) {
  logf("Choose mode %i", mode);
  for (int i = 0; i < FIVE; ++i) {
    if (allArrowBits[i]) {
      allArrowBits[i]->stop();
      allArrowBits[i] = NULL;
    }
  }

  if (millis() - lastModeChoose < 800 && pentaState.arrowIndex == mode) {
    // double tap on the current arrow: new palette for the automodes
    logf("new automode palette");
    automodePalette.randomizePalette();
  }
  pentaState.arrowIndex = mode;
  lastModeChoose = millis();
  indexedRunner->runPatternAtIndex(pentaState.arrowIndex);
  indexedRunner->setAlpha(0, false);

  storage.setValue(pentaState);

  patternManager.runOneShotPattern([] (PatternRunner &runner) {
    // spinning mirrored palette runs down the arrow
    const std::vector<PixelIndex> &arrow = arrows[pentaState.arrowIndex];
    BlinkPixelSet *pattern = new BlinkPixelSet(arrow, automodePalette.getPalette());
    pattern->fadeInDuration = 100;
    pattern->totalDuration = 600;
    pattern->fadeOutDuration = 400;
    return pattern;
  }, patternManager.highestPriority(), 0xFF);
}

// The chain shares one enable bitfield (see neighborhood.h); this runs
// whenever it changes, whether from our own long-press or a neighbor's.
static void automodesChanged(uint8_t bits) {
  pentaState.automaticModes = bits;
  storage.setValue(pentaState);
}
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
void loop() {
  if (serialTimeout && millis() - setupDoneTime < 1000) {
    serialTimeoutIndicator();
    return;
  }

  static bool firstLoop = true;
  if (firstLoop) {
    // startupWelcome();
    firstLoop = false;
  }  

  fftProcessing.frameReset();

#if LINK_DIAG
  link0.diagLoop(Serial); // wire-test commands + periodic state dumps (port 0)
#endif

  // Negotiate/maintain both inter-board links (orientation detection + framing).
  link0.update();
  link1.update();
#if HARDWARE_VERSION >= 2
  usbMux.update();    // computer or chain on J2? keep the mux pointed at what's there
#endif
  topology.update(); // probes the chain and tracks who is on each side
  neighborhoods.update(); // hop automode waves along the chain, launch new ones if we originate
  fwPush.update();    // firmware propagation sessions + auto-push to older neighbors

  // While an update is on the link, keep the wire clear of housekeeping traffic
  // (the push frames keep the link alive on their own).
  bool pushBusy = fwPush.sending() || fwPush.receiving();
  topology.setQuiet(pushBusy);
  neighborhoods.setQuiet(pushBusy);

  // While a firmware push is in flight, draw a determinate progress indicator
  // on the outer ring: two arcs that start at one USB port's end of the ring
  // and grow along both halves toward the other port's end, in the direction
  // the data is moving. Sending (green): from the far port toward the port the
  // update leaves through. Receiving (yellow): from the port the update
  // arrives on toward the far port, i.e. onward down the chain. Rides on top
  // of the running pattern (dimmed) and removes itself when the session ends.
  static bool updatePulseShown = false;
  if (pushBusy && !updatePulseShown) {
    updatePulseShown = true;
    patternManager.runOneShotDrawing([](DrawingContext &c, unsigned long) {
      bool sending = fwPush.sending(), receiving = fwPush.receiving();
      if (!sending && !receiving) return false;
      // Ring index nearest each USB-C port, from the PCB: J1/alt is at index 22
      // (pixel 92), J2/main at index 50 (pixel 120) -- opposite ends of the ring.
      static const int kRingIndexOfPort[2] = {22, 50};
      const int n = kCircleLedsInOrder.size();
      int port = fwPush.activePort();
      int from = sending ? kRingIndexOfPort[port ^ 1] : kRingIndexOfPort[port];
      int to   = sending ? kRingIndexOfPort[port]     : kRingIndexOfPort[port ^ 1];
      CRGB color = sending ? CRGB(0x00, 0xFF, 0x20) : CRGB(0xFF, 0xB0, 0x00);
      float progress = fwPush.progress();
      c.leds.fill_solid(CRGB::Black);
      // for (PixelIndex px : kCircleLedsInOrder) c.leds[px] = color.scale8(12); // faint track
      // one arc each way around the ring, from `from` toward `to`
      for (int dir = -1; dir <= 1; dir += 2) {
        int span = ((to - from) * dir % n + n) % n; // pixels from `from` to `to` in this direction
        float lit = progress * span;
        for (int k = 0; k <= span; k++) {
          float f = lit - k; // how much of pixel k along the arc is lit
          if (f <= 0) break;
          uint8_t level = f >= 1 ? 0xFF : (uint8_t)(f * 0xFF);
          c.leds[kCircleLedsInOrder[((from + dir * k) % n + n) % n]] = color.scale8(level);
        }
      }
      return true;
    }, patternManager.highestPriority(), 0xFF);
  } else if (!pushBusy) {
    updatePulseShown = false;
  }

  // Serial console, one command per line (like motionhexa's): the Newer Glow updater's IDENTIFY / BLINK,
  // "HWTEST [verdict]" (no verdict starts the self-test, PASS/WARN/FAIL shows the host's), and the bench commands below.
  char *serialLine = readSerialLine();
  if (serialLine) {
    updater->loop(serialLine);
#if HARDWARE_VERSION >= 2
    if (strncmp(serialLine, kHWTestCommand, strlen(kHWTestCommand)) == 0) {
      const char *arg = serialLine + strlen(kHWTestCommand);
      while (*arg == ' ') ++arg;
      hwTest.command(arg);
    }
#endif
    if (strcmp(serialLine, "TOPOLOGY") == 0) {
      topology.logState();
    } else if (strcmp(serialLine, "HW") == 0) { // boot-time facts, on demand
      logf("penta %s build %lu (%s %s)", FW_VERSION, (unsigned long)BUILD_EPOCH, __DATE__, __TIME__);
#if HARDWARE_VERSION >= 2
      logf("usb mux select pulldown R15: %s", selectPulledLow ? "present" : "MISSING");
      logf("usb mux: %s (host %s)", usbMux.stateName(), usbMux.hostPresent() ? "present" : "absent");
#endif
      logf("mic streaming: %s%s", audioInput.isStreaming() ? "yes" : "no", audioInput.selectReleased() ? " (SELECT released: v2 floating mic ground)" : "");
      verifyPioLayout();
    } else if (strcmp(serialLine, "WAVE") == 0 || strncmp(serialLine, "WAVE ", 5) == 0) { // start automode n's wave from here (default 0)
      neighborhoods.start(serialLine[4] ? constrain(atoi(serialLine + 5), 0, 4) : 0);
    } else if (strcmp(serialLine, "NEIGHBORS") == 0) {
      neighborhoods.logState();
    } else if (strcmp(serialLine, "PATTERN") == 0) { // next pattern, as if the next arrow were tapped
      chooseMode((pentaState.arrowIndex + 1) % FIVE);
    } else if (strncmp(serialLine, "PATTERN ", 8) == 0) {
      chooseMode(constrain(atoi(serialLine + 8), 0, FIVE - 1));
    } else if (strcmp(serialLine, "PUSH") == 0) { // push our firmware to a neighbor
      fwPush.pushAll();
    } else if (strcmp(serialLine, "PULL") == 0) { // ask a neighbor to push its firmware to us
      fwPush.pullAny();
    } else if (strcmp(serialLine, "REBOOT") == 0) {
      logf("rebooting");
      Serial.flush();
      rp2040.reboot();
    } else if (strcmp(serialLine, "BOOTSEL") == 0) {
      logf("rebooting to bootloader");
      Serial.flush();
      rp2040.rebootToBootloader();
    }
  }

  // // Demo traffic: once linked, send a heartbeat on each port every second.
  // static unsigned long lastHeartbeat = 0;
  // if (millis() - lastHeartbeat >= 1000) {
  //   lastHeartbeat = millis();
  //   if (link0.isLinked()) link0.send("hello-p0");
  //   if (link1.isLinked()) link1.send("hello-p1");
  // }

  FastLED.setBrightness(kDefaultBrightness);
#if HARDWARE_VERSION >= 2
  if (hwTest.active()) {
    hwTest.loop(); // the self-test owns the pixels for its few seconds; the power gate and show below still run
  } else
#endif
  patternManager.loop();
  controls.update();

  bool pixelsNeedPower = true;
  static bool pixelsHavePower = false;
  static unsigned long lastPixelsNeedPower = 0;
  pixelsNeedPower = ctx.leds;
  if (pixelsNeedPower) {
    lastPixelsNeedPower = millis();
  }
  if (pixelsNeedPower != pixelsHavePower 
    && (pixelsNeedPower || millis() - lastPixelsNeedPower > 500)) { // don't turn off panel for very brief periods
    logf("Turn %s pixels", pixelsNeedPower?"on":"off");

    digitalWrite(LED_LINE_0_POWER, pixelsNeedPower);
    pixelsHavePower = pixelsNeedPower;

    if (pixelsNeedPower) {
      // reset the pin after using it for gpio (assume fastled on pio0)
      gpio_set_function(LED_DATA, GPIO_FUNC_PIO0);
    } else {
      // we low-side switch, so when the gnd is disconnected, a small amount of curent is still flowing thru pixel 0 data line, which is driven low from drawing #000000
      assert(gpio_get_function(LED_DATA) == GPIO_FUNC_PIO0, "LED_DATA not PIO?");
      pinMode(LED_DATA, OUTPUT);
      gpio_put(LED_DATA, true);
    }
  }


  if (pixelsHavePower) {
    FastLED.show();
  }
  ambientSound->ambientLevel(); // drain the mic every frame to keep it accurate
  
  fc.loop();
  fc.clampToFramerate(240);
}

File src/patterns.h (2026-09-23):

#ifndef PATTERN_H
#define PATTERN_H

#include <FastLED.h>

#include <util.h>
#include <drawing.h>

#include "paletting.h"
#include "ledgraph.h"
#include "particles.h"
#include "remembering.h"
#include "neighborhood.h"

using Particles = ParticleSim<LED_COUNT>;

struct PentaState : Persistable {
  uint8_t arrowIndex=0;
  uint8_t colorIndex=0; // unused
  uint8_t automaticModes=0; // bitfield
  static constexpr size_t dataSize() {
    // FIXME: sizeof(PentaState) == 8, because we get some size added by using virtual functions in Persistable here. not sure if I need these high level coding practices.
    return 3;
  }

  virtual String serialize() {
    logdf("PentaState serialize!");
    uint8_t bytes[3] = {arrowIndex, colorIndex, automaticModes};
    String serialized(bytes, 3);
    return serialized;
  }
  virtual void deserialize(String data) {
    assert(data.length() == dataSize(), "deserialize got data of length %i", data.length());
    if (data.length() >= 3) {
      arrowIndex = data[0];
      colorIndex = data[1];
      automaticModes = data[2];
    }
  }
  void log() {
    logf("PentaState: %i %i %i", arrowIndex, colorIndex, automaticModes);
  }
};
PentaState pentaState;

// One palette shared by every automode and by the arrow flash that previews it.
// double tap for new new palette
PaletteRotation<CRGBPalette256> automodePalette(/*minBrightness*/ 20);

// Where this unit sits in the shared palette: chain positions spread over the
// palette's 0..0xFF range, so a wave running down the chain sweeps through it.
uint8_t neighborhoodPaletteIndex() {
  int total = max(1, topology.total());
  return 0xFF * topology.position() / total;
}
CRGB neighborhoodColor() {
  return automodePalette.getPaletteColor(neighborhoodPaletteIndex());
}

/* ------------------------------------------------------------------------------- */

class BlinkPixelSet : public Pattern {
  const std::vector<PixelIndex> pixelSet; // yes i know it's a vector not a set
  CRGB color;
  CRGBPalette256 palette;
  bool isPalette = false;
public:
  unsigned long fadeInDuration;
  unsigned long fadeOutDuration;
  unsigned long totalDuration;
  BlinkPixelSet(const std::vector<PixelIndex> pixelSet, CRGB color, unsigned long fadeInDuration=0, unsigned long fadeOutDuration=0, unsigned long totalDuration=0) 
    : pixelSet(pixelSet), color(color), isPalette(false), fadeInDuration(fadeInDuration), fadeOutDuration(fadeOutDuration), totalDuration(totalDuration) {
      assert(totalDuration == 0 || totalDuration >= fadeInDuration + fadeOutDuration, "need time to fade in and out");
    }
  BlinkPixelSet(const std::vector<PixelIndex> pixelSet, CRGBPalette256 palette, unsigned long fadeInDuration=0, unsigned long fadeOutDuration=0, unsigned long totalDuration=0) 
    : pixelSet(pixelSet), palette(palette), isPalette(true), fadeInDuration(fadeInDuration), fadeOutDuration(fadeOutDuration), totalDuration(totalDuration) {
      assert(totalDuration == 0 || totalDuration >= fadeInDuration + fadeOutDuration, "need time to fade in and out");
    }
  void update() {
    if (totalDuration > 0 && runTime() > totalDuration) {
      stop();
    } else {
      uint8_t fade = 0xFF;
      if (fadeInDuration > 0) {
        fade = min(0xFF, 0xFF * runTime() / fadeInDuration);
      }
      if (fadeOutDuration > 0) {
        fade = scale8(fade, min(0xFF, 0xFF * (totalDuration - runTime()) / fadeOutDuration));
      }
      
      int i = 0;
      for (PixelIndex idx : pixelSet) {
        CRGB drawColor = (isPalette ? PaletteRotation<CRGBPalette256>::getMirroredPaletteColor(palette, millis()/2 + 0x1FF*i++/pixelSet.size()) : color);
        drawColor = drawColor.scale8(ease8InOutCubic(fade));
        ctx.leds[idx] = drawColor;
      }
    }
  }
  const char *description() {
    return "BlinkPixelSet";
  }
};

class BlinkFiveTriangles : public Pattern {
  unsigned long duration;
public:
  BlinkFiveTriangles(unsigned long duration) : duration(duration) { }
  void update() {
    ctx.leds.fill_solid(CRGB::Black);
    // Each triangle fades in and out over blinkLen, each next triangle's animation overlaps the previous
    const unsigned long blinkLen = duration / 3;
    const unsigned long stagger = blinkLen / 2;
    unsigned long rt = runTime();
    for (int t = 0; t < FIVE; ++t) {
      unsigned long t0 = t * stagger;
      if (rt < t0 || rt >= t0 + blinkLen) {
        continue;
      }
      // Triangular 0..255..0 envelope across the blink, smoothed to a sine-ish curve
      uint8_t phase = 0xFF * (rt - t0) / blinkLen;
      uint8_t brightness = ease8InOutCubic(triwave8(phase));
      int point = (t + topology.position()) % FIVE; // each unit in the chain starts one triangle over
      uint8_t paletteIndex = neighborhoodPaletteIndex() + 0xFF * point / FIVE;
      CRGB dimmed = automodePalette.getPaletteColor(paletteIndex, brightness);
      auto theset = pentaTriangles[point];
      for (auto px : theset) {
        ctx.point(px, dimmed, blendBrighten);
      }
    }
  }
  const char *description() {
    return "BlinkFiveTriangles";
  }
};

/* ------------------------------------------------------------------------------- */

class StarMazePattern : public Pattern, PaletteRotation<CRGBPalette256> {
  Particles bitsFiller;
public:
  StarMazePattern() : bitsFiller(ledgraph, ctx, 1, 90, 0, {EdgeType::starwise}) {
    bitsFiller.spawnPixels = &kStarwiseLeds;
  }
  void update() {
    bitsFiller.particles[0].color = getShiftingPaletteColor(0, FIVE);
    bitsFiller.update();
  }

  const char *description() {
    return "StarMazePattern";
  }
};

// Automode: one dot sweeps the star, colored from the shared automode palette.
class StarwisePattern : public Pattern {
public:
  unsigned long cycleMillis;
  StarwisePattern(unsigned long cycleMillis=1000) : cycleMillis(cycleMillis) { }
  void update() {
    ctx.leds.fadeToBlackBy(4);
    uint8_t curIndex = (kStarwiseLeds.size() * millis()/cycleMillis) % kStarwiseLeds.size();
    CRGB paletteColor = automodePalette.getShiftingPaletteColor(neighborhoodPaletteIndex() + curIndex, FIVE*FIVE);
    ctx.leds[kStarwiseLeds[curIndex]] = paletteColor;
  }

  const char *description() {
    return "StarwisePattern";
  }
};

/* ------------------------------------------------------------------------------- */
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

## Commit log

2023-11-15 initial pixel layout concept
    [penta.kicad_pcb, penta.kicad_sch]
2023-12-06 candidate pixel layout + RP2040 + microphone + USB
    [penta.kicad_pcb, penta.kicad_sch]
2023-12-08 remove the 5v net
    [penta.kicad_pcb]
2023-12-24 schematic for a boost chip that we may not actually need; + wc changes
    [penta.good.kicad_pcb, penta.kicad_pcb, penta.kicad_sch]
2025-01-11 completely rework everything but the pixels; base it off seeeduino for ease/cost; add a usb port for chaining; add a microphone
    [penta.good.kicad_pcb, penta.kicad_pcb, penta.kicad_sch]
2025-01-11 myriad improvements. mounting points for idk, nice symmetric. removed unnecessary pads from seeduino footprint to make room for mount points; added exposed ldo VIN pin to seeduino footprint bc it's V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
    [penta.kicad_pcb, penta.kicad_sch, penta.step]
2025-01-11 add 3 gpios to the screwmounts, which are now thts. maybe these can be used for capacitive touch?
    [penta.kicad_pcb, penta.kicad_sch]
2025-01-15 add an nfet so we can power down pixels for whatever saves that'll get doing larger pattern work; make 4-layer board to support switching a gnd plane off; decorate
    [penta.kicad_pcb, penta.kicad_sch]
2025-01-15 make a real quick usb coupler intended to be printed on flexible pcb
    [ded.kicad_pcb, ded.kicad_sch]
2025-01-16 pins rearrangement to make touch pads work; minor fixes and polish
    [penta.kicad_pcb, penta.kicad_sch]
2025-01-16 ok. support all 5 touch pins because we can
    [penta.kicad_pcb, penta.kicad_sch]
2025-01-17 exclude touch fps from bom
    [penta.kicad_pcb, penta.kicad_sch]
2025-01-17 add a hopefully-more-bendable spot to the usb coupler; fix drc; add sds
    [ded.kicad_pcb, ded.kicad_sch]
2025-01-25 candidate designs for ded and deh couplers
    [ded.kicad_pcb, ded.kicad_sch, deh.kicad_pcb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]
2025-01-29 layout on ded to make it a little shorter and give the thts a little more space
    [ded.kicad_pcb]
2025-01-29 ded: add stiffener layer
    [ded.kicad_pcb]
2025-01-31 checkpoint: BitsFiller fixes for split mode, added some new options, add continueTo edgeType for bits to move thru intersections; new patterns FiveBitsPattern, BreadthFirstPattern, TrianglePointSourc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
    [ledgraph.h, main.cpp, patterns.h]
2025-01-31 make TrianglePointSource better; start working on a better button scheme
2025-02-12 ded stiffener fixes from last week's production rev
    [ded.kicad_pcb]
2025-02-19 fix a long-standing FIXME involving particle fade-up, where fadeup didn't work with random path selection; should also improve performance at the cost of some memory, though I have not measured this
    [patterns.h]
2025-02-19 change BitsFiller fadeDown to be per 1/256 millisecond for finer-grained fadeDown configuration; use it + the new fadeUp improvements to make the BreadthFirst pattern look less frenetic
2025-08-16 drop in an rp2040 and associated circuitry; proper usb port (two of them); bottom-facing mic; do a first pass on layout
    [penta.kicad_pcb, penta.kicad_sch]
2025-09-02 add a usb mux for communicating between pentas and make a draft layout
    [penta.kicad_pcb, penta.kicad_sch]
2025-09-03 polish & readiness
    [penta.kicad_pcb, penta.kicad_sch]
2025-09-03 exclude swd pins from pos file
    [penta.kicad_pcb]
2025-09-16 commit some code i mostly wrote months ago but never felt was finished. this reworks the touch button system to toggle on or off FIVE periodic patterns, along with some animations to soft of indicate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
    [ledgraph.h, main.cpp, patterns.h]
2026-03-25 fix powering pixels on and off as needed
    [main.cpp]
2026-08-28 uart communication is working via a software uart with careful pio allocation and a pin toggling negotiation protocol
2026-08-29 i did the freaking mosfet wrong *again*
    [penta.kicad_pcb, penta.kicad_sch]
2026-08-29 fix microphone GND connection (it didn't have one?! but is still working fine?!)
    [penta.kicad_pcb]
2026-08-29 kicad format update
    [penta.kicad_pcb, penta.kicad_sch]
2026-08-29 minor layout tweaks and drc
    [penta.kicad_pcb]
2026-08-29 mosfet GSD was actually correct so change it back. the dim pixel issue was current leaking through data line, already fixed in software in main
    [penta.kicad_pcb, penta.kicad_sch]
2026-08-29 many passives -> Basic JLC parts; fix mirrored silkscreen labels; fix Q1 missing a footprint in sch
    [penta.kicad_pcb, penta.kicad_sch]
2026-09-02 ded revision: new usb part, better trace/via routing for stability, better stiffener plan
    [ded.kicad_pcb, ded.kicad_sch]
2026-09-17 coupler usb part change
    [ded.kicad_pcb, ded.kicad_sch]
2026-09-17 uart toplogy self-discovery and update propagation! needs review.
2026-09-22 better sound leveling for penta - realize that pixel noise is definitely messing with the microphone
    [main.cpp, patterns.h]
2026-09-22 fix FiveBitsPattern; broken recently by dustlib moving to choose-randomly-between-edges-of-same-priority
    [patterns.h]
2026-09-23 concept: fivebitspattern synchronized over the neighborhood, no longer run via Particles. needs review
    [main.cpp, neighborhood.h, patterns.h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]
2026-09-25 pin fastled
